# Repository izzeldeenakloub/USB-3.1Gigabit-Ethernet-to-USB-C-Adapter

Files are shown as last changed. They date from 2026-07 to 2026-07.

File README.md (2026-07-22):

# HelloBoardPCB

A KiCad design project for a **USB-C to Gigabit Ethernet adapter** and my first complete 4-layer PCB layout.

## Project Purpose

This project was created as a proof of concept to practice:

- Four-layer PCB stack-up design
- USB-C connector integration
- Gigabit Ethernet routing and component placement
- Ground and power plane organization
- Differential-pair placement and routing
- KiCad schematic and PCB layout workflows

## Current Status

The schematic and initial PCB placement/routing have been completed.

However, this revision is **not production-ready** and has not been fabricated or electrically tested. Some Design Rule Check errors remain because the initial layout was completed before properly configuring:

- PCB manufacturer design constraints
- Net classes
- Differential-pair rules
- Track widths and clearances
- Via sizes
- Controlled-impedance requirements

The current revision should therefore be treated as a **layout study and proof-of-concept design**, rather than a validated manufacturing release.

A revised version with properly configured constraints, corrected DRC issues, and manufacturing files is planned.

## Current Schematic

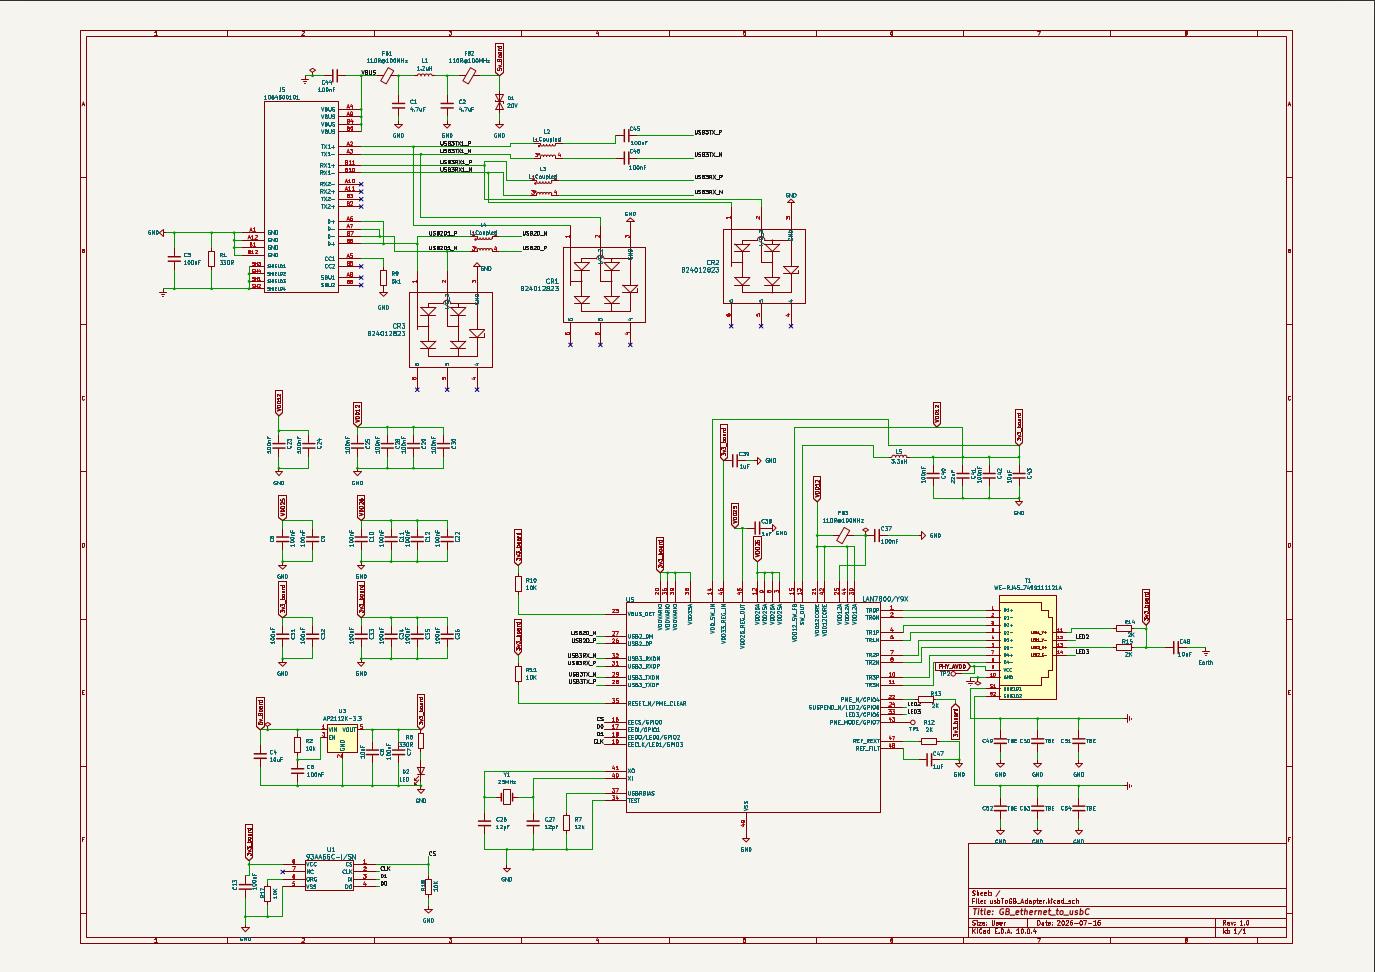
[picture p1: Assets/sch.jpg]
Current Schematic


## Current PCB Layout

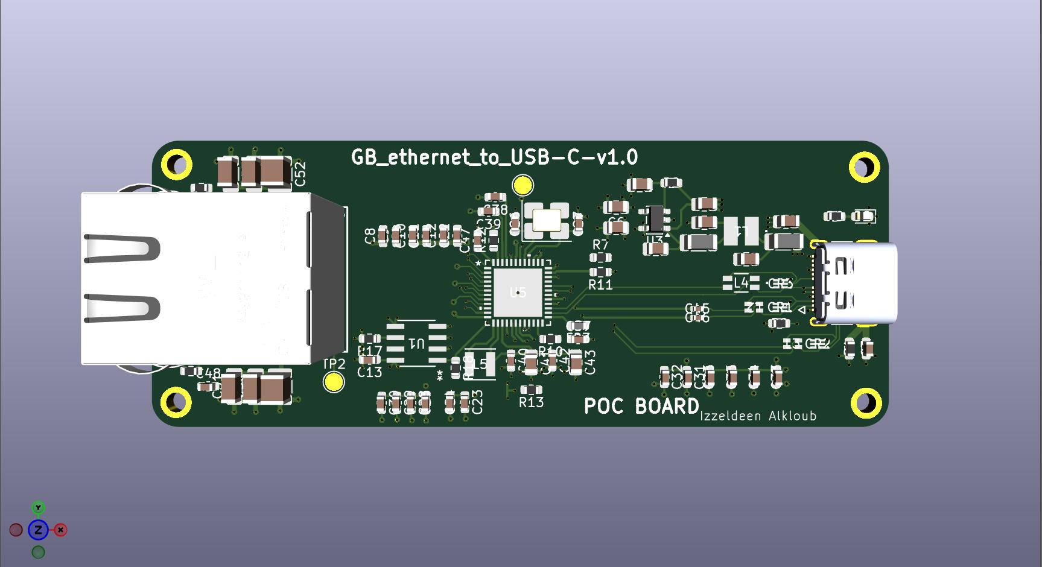
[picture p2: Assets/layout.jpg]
Current PCB Layout


## Planned Improvements

- Configure manufacturer-specific design rules
- Create dedicated USB 2.0, USB 3.x, Ethernet, power, and general-signal net classes
- Set appropriate differential-pair widths and spacing
- Review high-speed signal return paths
- Correct remaining ERC and DRC violations
- Review grounding and chassis/Earth connections
- Generate Gerber, drill, BOM, and pick-and-place files
- Perform a final manufacturability review

## Tools

- KiCad
- Four-layer PCB stack-up:
  - Front copper: components and signals
  - Inner layer 1: ground plane
  - Inner layer 2: power distribution
  - Back copper: signals

## Disclaimer

This repository currently documents my PCB design and learning process. The board should not be manufactured from the current files without completing a full electrical, mechanical, signal-integrity, and design-rule review.

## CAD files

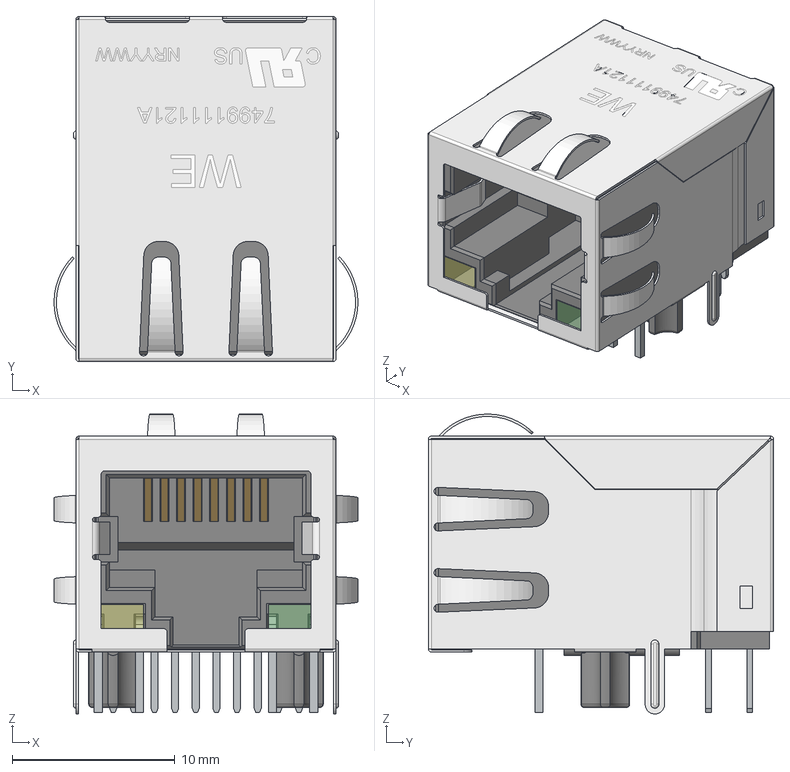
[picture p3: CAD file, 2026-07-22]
ExternalSymbols&Footprint/rj45/rj45(a)/WE-RJ45_7499111121A.step
18.7 x 21.2 x 18.5 mm

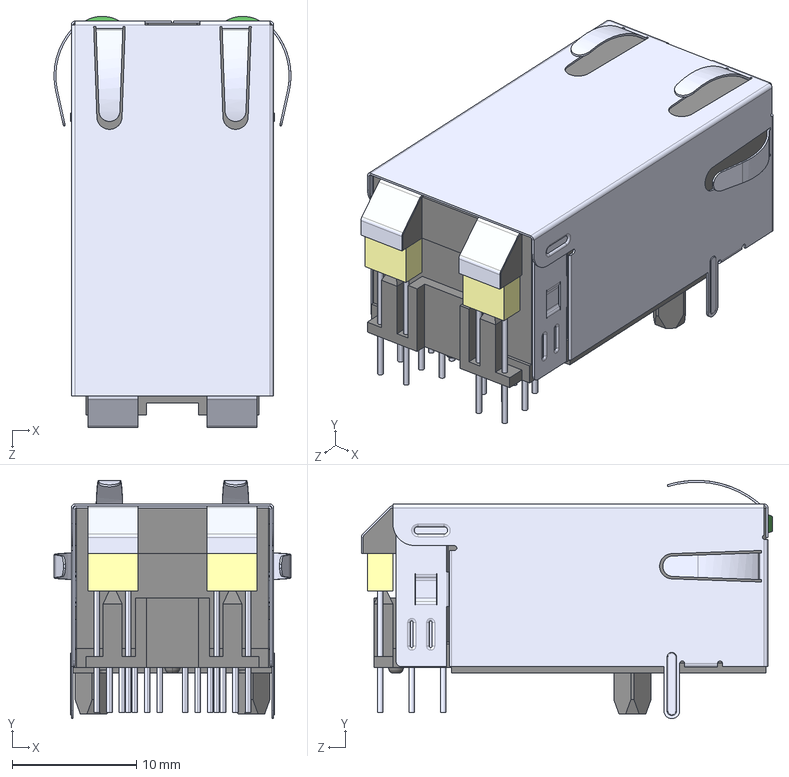
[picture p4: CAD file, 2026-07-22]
ExternalSymbols&Footprint/rj45/rj45(b)/0826-1G1T-23-F.step
19.1 x 19.2 x 33.1 mm

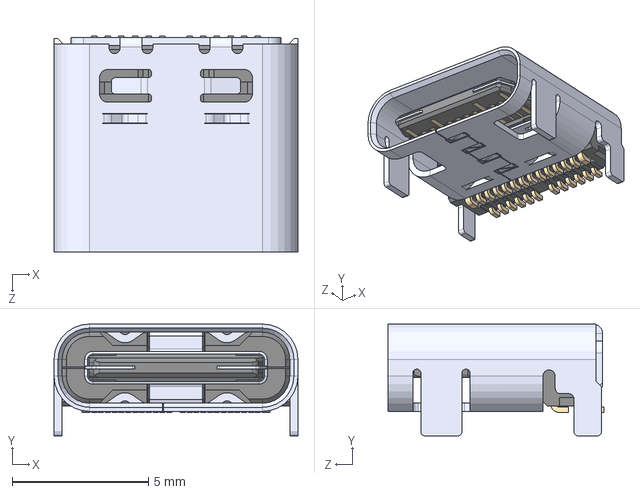
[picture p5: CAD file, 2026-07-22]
ExternalSymbols&Footprint/usb-c/usb-c_2/1054500101.step
8.94 x 4.10 x 7.90 mm

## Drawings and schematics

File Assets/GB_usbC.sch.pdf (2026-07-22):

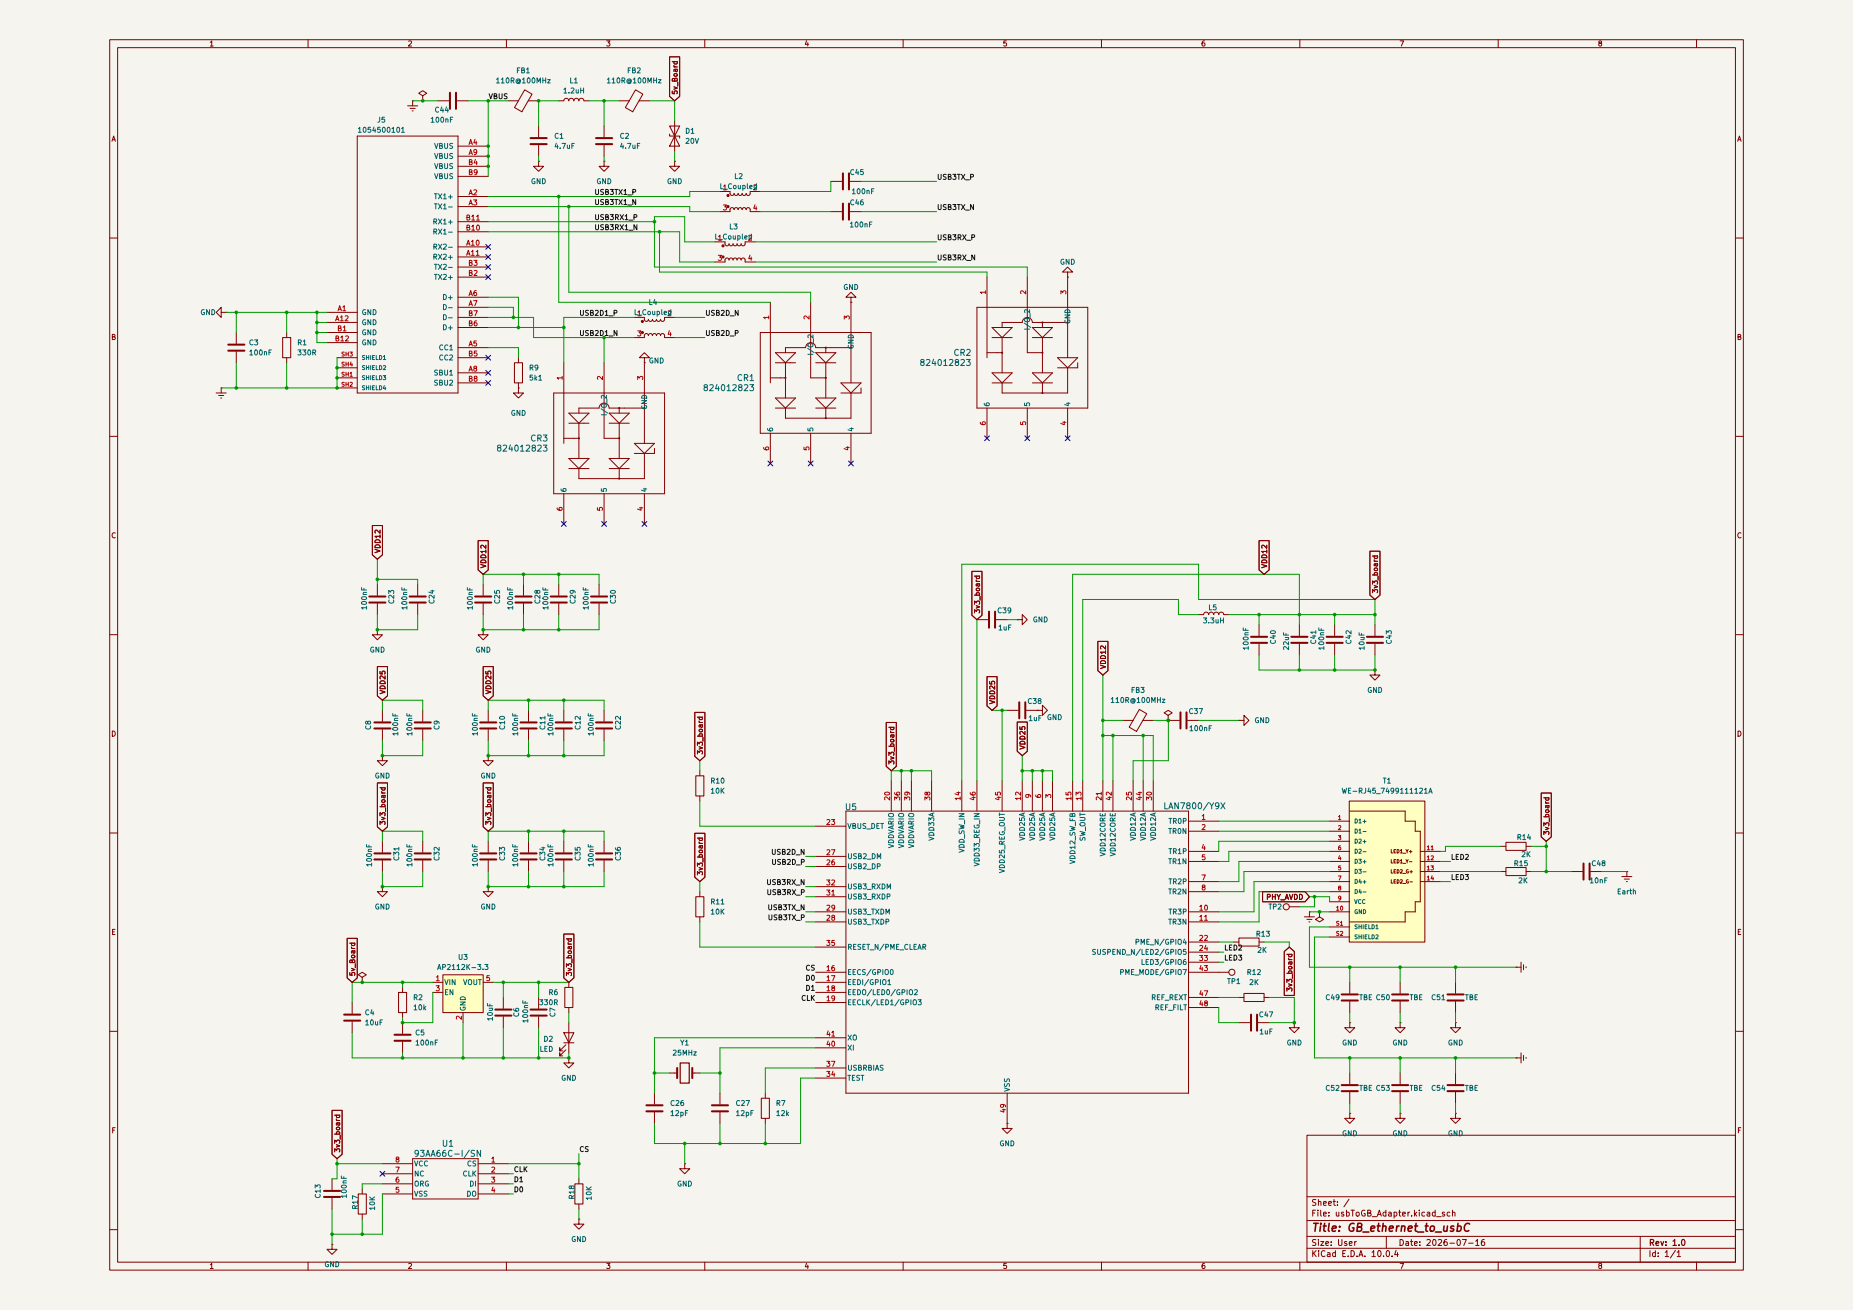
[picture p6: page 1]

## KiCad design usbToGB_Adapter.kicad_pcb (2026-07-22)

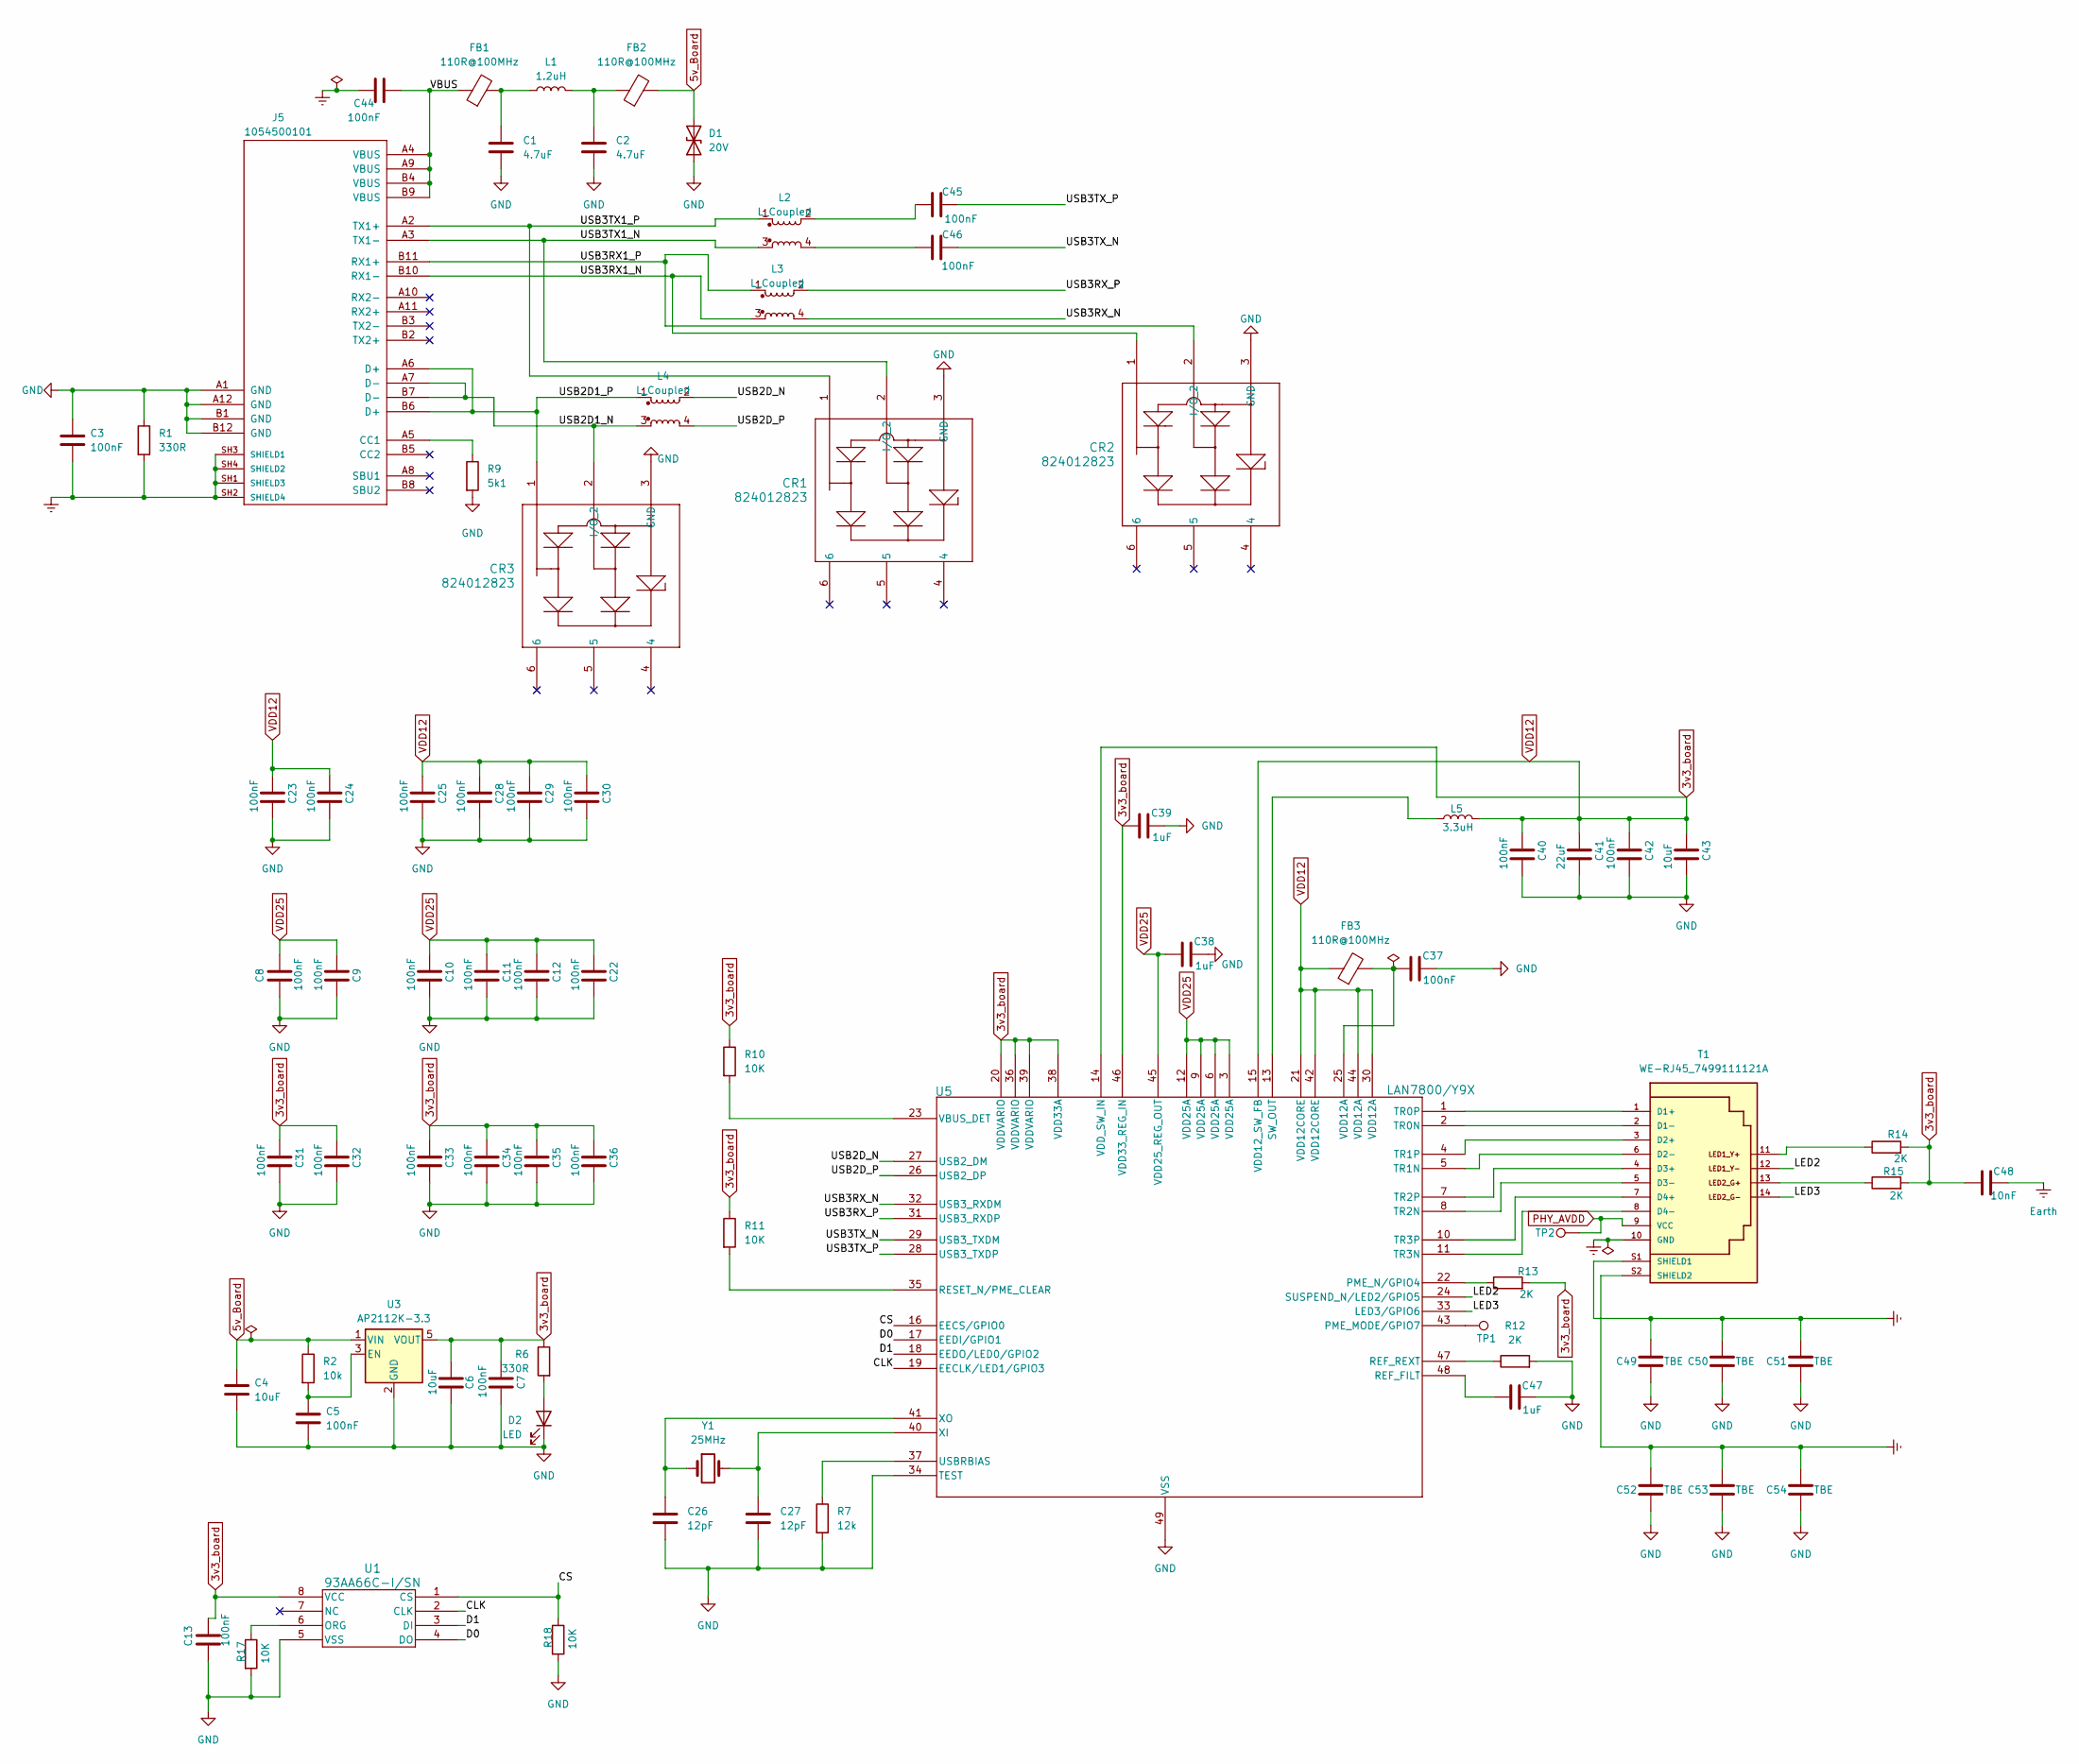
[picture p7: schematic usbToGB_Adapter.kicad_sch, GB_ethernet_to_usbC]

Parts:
C1, C2: 4.7uF; C_0805_2012Metric
C3, C8, C9, C10, C11, C12, C13, C22, C23, C24, C25, C28, C29, C30, C31, C32, C33, C34, C35, C36, C37, C40, C42: 100nF; C_0603_1608Metric
C4, C6, C43: 10uF; C_0805_2012Metric
C5, C7, C44: 100nF; C_0805_2012Metric
C26, C27: 12pF; C_0603_1608Metric
C38, C39, C47: 1uF; C_0603_1608Metric
C41: 22uF; C_0805_2012Metric
C45, C46: 100nF; C_0402_1005Metric
C48: 10nF; C_0603_1608Metric
C49, C52: TBE; C_1210_3225Metric
C50, C51, C53, C54: TBE; C_1206_3216Metric
CR1, CR2, CR3: 824012823; DFN_012823_WRE
D1: 20V; C_0805_2012Metric
D2: LED; LED_0603_1608Metric
FB1, FB2: 110R@100MHz; L_1206_3216Metric
FB3: 110R@100MHz; L_0603_1608Metric
J5: 1054500101; MOLEX_1054500101; PARTREV A7
L1: 1.2uH; IND_WE-MAPI_3020_WRE
L2, L3: L_Coupled; CHIP_35600_WRE
L4: L_Coupled; SMT_32090_WRE
L5: 3.3uH; IND_WE-LQS_3015_WRE
R1, R6: 330R; R_0603_1608Metric
R2: 10k; R_0603_1608Metric
R7: 12k; R_0603_1608Metric
R9: 5k1; R_0603_1608Metric
R10, R11, R17, R18: 10K; R_0603_1608Metric
R12, R13, R14, R15: 2K; R_0603_1608Metric
T1: WE-RJ45_7499111121A; 7499111121A
TP1, TP2: TestPoint; TestPoint_Pad_D2.0mm
U1: 93AA66C-I/SN; SOIC8-N_MC_MCH
U3: AP2112K-3.3; SOT-23-5
U5: LAN7800/Y9X; SQFN48_7X7_Y9X_MCH
Y1: 25MHz; Crystal_SMD_3225-4Pin_3.2x2.5mm_HandSoldering

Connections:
5v_Board: C4.1, D1.2 (A2), FB2.2, R2.1, U3.1 (VIN)
/CLK: U1.2 (CLK), U5.19 (EECLK/LED1/GPIO3)
/CS: R18.1, U1.1 (CS), U5.16 (EECS/GPIO0)
/D0: U1.4 (DO), U5.17 (EEDI/GPIO1)
/D1: U1.3 (DI), U5.18 (EEDO/LED0/GPIO2)
/LED2: T1.12, U5.24 (SUSPEND_N/LED2/GPIO5)
/LED3: T1.14, U5.33 (LED3/GPIO6)
/USB2D1_N: CR3.2 (I/O_2), J5.A7 (D-), J5.B7 (D-), L4.3
/USB2D1_P: CR3.1, J5.A6 (D+), J5.B6 (D+), L4.1
/USB2D_N: L4.2, U5.27 (USB2_DM)
/USB2D_P: L4.4, U5.26 (USB2_DP)
/USB3RX1_N: CR2.1, J5.B10 (RX1-), L3.3
/USB3RX1_P: CR2.2 (I/O_2), J5.B11 (RX1+), L3.1
/USB3RX_N: L3.4, U5.32 (USB3_RXDM)
/USB3RX_P: L3.2, U5.31 (USB3_RXDP)
/USB3TX1_N: CR1.2 (I/O_2), J5.A3 (TX1-), L2.3
/USB3TX1_P: CR1.1, J5.A2 (TX1+), L2.1
/USB3TX_N: C46.1, U5.29 (USB3_TXDM)
/USB3TX_P: C45.1, U5.28 (USB3_TXDP)
/VBUS: C44.2, FB1.1, J5.A4 (VBUS), J5.A9 (VBUS), J5.B4 (VBUS), J5.B9 (VBUS)
<NO NET>: T1.10 (GND)
Earth: C3.2, C44.1, C48.2, C49.2, C50.2, C51.2, C52.2, C53.2, C54.2, J5.SH1 (SHIELD3), J5.SH2 (SHIELD4), J5.SH3 (SHIELD1), J5.SH4 (SHIELD2), R1.2, T1.S1 (SHIELD1), T1.S2 (SHIELD2)
unnamed: C1.2, FB1.2, L1.1
unnamed: C2.2, FB2.1, L1.2
unnamed: C37.1, FB3.2, U5.25 (VDD12A)
unnamed: C45.2, L2.2
unnamed: C46.2, L2.4
unnamed: D2.2 (A), R6.2
unnamed: J5.A5 (CC1), R9.1
unnamed: R14.1, T1.11
unnamed: R15.1, T1.13
unnamed: T1.1 (D1+), U5.1 (TR0P)
unnamed: T1.2 (D1-), U5.2 (TR0N)
unnamed: T1.3 (D2+), U5.4 (TR1P)
unnamed: T1.6 (D2-), U5.5 (TR1N)
unnamed: T1.4 (D3+), U5.7 (TR2P)
unnamed: T1.5 (D3-), U5.8 (TR2N)
unnamed: T1.7 (D4+), U5.10 (TR3P)
unnamed: T1.8 (D4-), U5.11 (TR3N)
unnamed: R17.1, U1.6 (ORG)
unnamed: C5.1, R2.2, U3.3 (EN)
unnamed: TP1.1 (1_1), U5.43 (PME_MODE/GPIO7)
unnamed: R13.1, U5.22 (PME_N/GPIO4)
unnamed: C47.1, U5.48 (REF_FILT)
unnamed: R12.1, U5.47 (REF_REXT)
unnamed: R11.2, U5.35 (RESET_N/PME_CLEAR)
unnamed: L5.1, U5.13 (SW_OUT)
unnamed: R7.1, U5.37 (USBRBIAS)
unnamed: R10.2, U5.23 (VBUS_DET)
unnamed: C27.1, U5.40 (XI), Y1.2
unnamed: C26.1, U5.41 (XO), Y1.1
PHY_AVDD: T1.9 (VCC), TP2.1 (1_1)

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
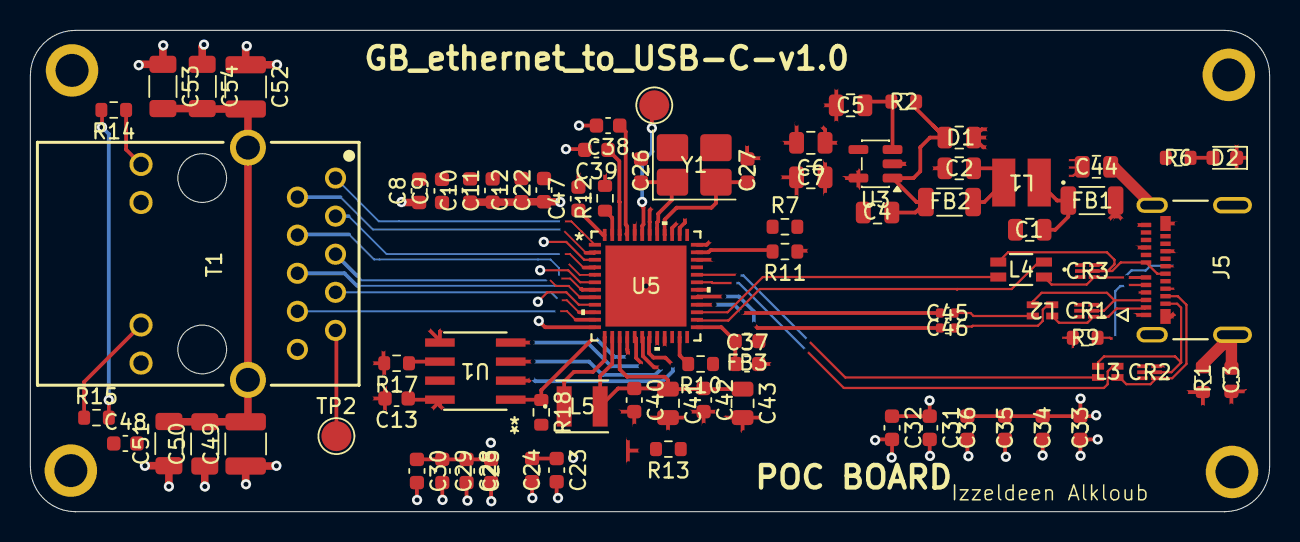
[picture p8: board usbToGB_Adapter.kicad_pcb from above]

Board: 4 copper layers, 82.7 x 32.1 mm, 80 parts (0 on the bottom side), 54 nets.

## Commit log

2026-07-16 Initial commit: LAN7800-based USB-C Gigabit Ethernet adapter schematic and project files
    [usbToGB_Adapter.kicad_pcb, usbToGB_Adapter.kicad_sch]
2026-07-22 feat
    add complete schematic and initial 4-layer PCB layout
    [0826-1G1T-23-F.step, 1054500101.step, 7499111121A+%28rev1%29.stp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]
